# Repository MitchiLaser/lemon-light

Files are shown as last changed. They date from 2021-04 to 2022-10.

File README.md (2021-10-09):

# lemon-light
a couple of people trying to build a fancy monochrome LED display with bottles

## used bottles
We used lemonade bottles with 500 ml infill. The drinks boxes we bougth them inside had space for 26 bottles (4 x 6) and had a surface of 30cm x 40cm. Every box has its own controller which receives data via UART and drives the LEDs. The controllers can be connected in a dasy chain configuration.

## controllerboards

### slave

Every drink box has its own slave controller which is nothing more then an Attiny85 and 3 74hc595 shift registers. The Attiny receives the data via a UART interface, gets the first 3 bytes ans sends the rest to the next controller (also UART). Furthermore there is also an lm7805 attached because all boxes are powered via a voltage higher then 7,5V. This decision was made to prevent a voltage drop.

### master

The whole display is being controlled by a single master-controller which is made out of an ESP8266 and some electronics to translate the voltage for the serial interface between 3,3V and 5V. It is connected to a WiFi-interface and provides a web interface to control the boxes.

## 3D objects

There are some 3d printed objects that were used in the original build of this project: A part to hold the leds in the bottles and a box for the slave controller.

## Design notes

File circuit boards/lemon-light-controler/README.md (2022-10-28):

Main Controller Design
===
- parts used
  - node MCU
  - small buck converter breakout board
  - SN74HCT245N (although a one channel version of it would be better)
  - screw terminals for power supply and TX
- design
  - soldered on a breadboard
  - the buck converter provides 5V power supply
  - the RX pin is shifted with the SN74HCT245N from the 3.3V to the 5V level
- notes
  - make sure not to pull the TX of the node MCU low during boot
    (if you use a different level shifter)
  - during boot some data is output which causes the display to show random stuff
    - could be avoided by connecting the output enable pin of the SN74HCT245N
      to some GPIO of the node mcu

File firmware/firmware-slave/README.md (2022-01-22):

# Firmware for the slaves 
compile firmware with arduino ide and tinyMircroCore

## upload
use pyupdi

```pyupdi -d tiny406 -f firmware-slave.hex --fuses 2:0x02 6:0x04 8:0x00 -c /dev/ttyUSBx```

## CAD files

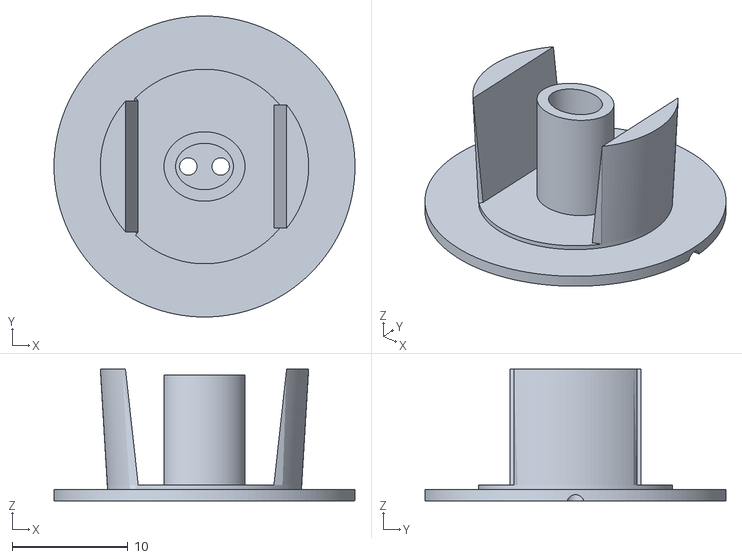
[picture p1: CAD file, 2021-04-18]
3d-objects/led_holder/HoliLight_led_holder.stl
26.0 x 26.0 x 11.4

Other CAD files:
3d-objects/led_holder/HoliLight_led_holder.blend

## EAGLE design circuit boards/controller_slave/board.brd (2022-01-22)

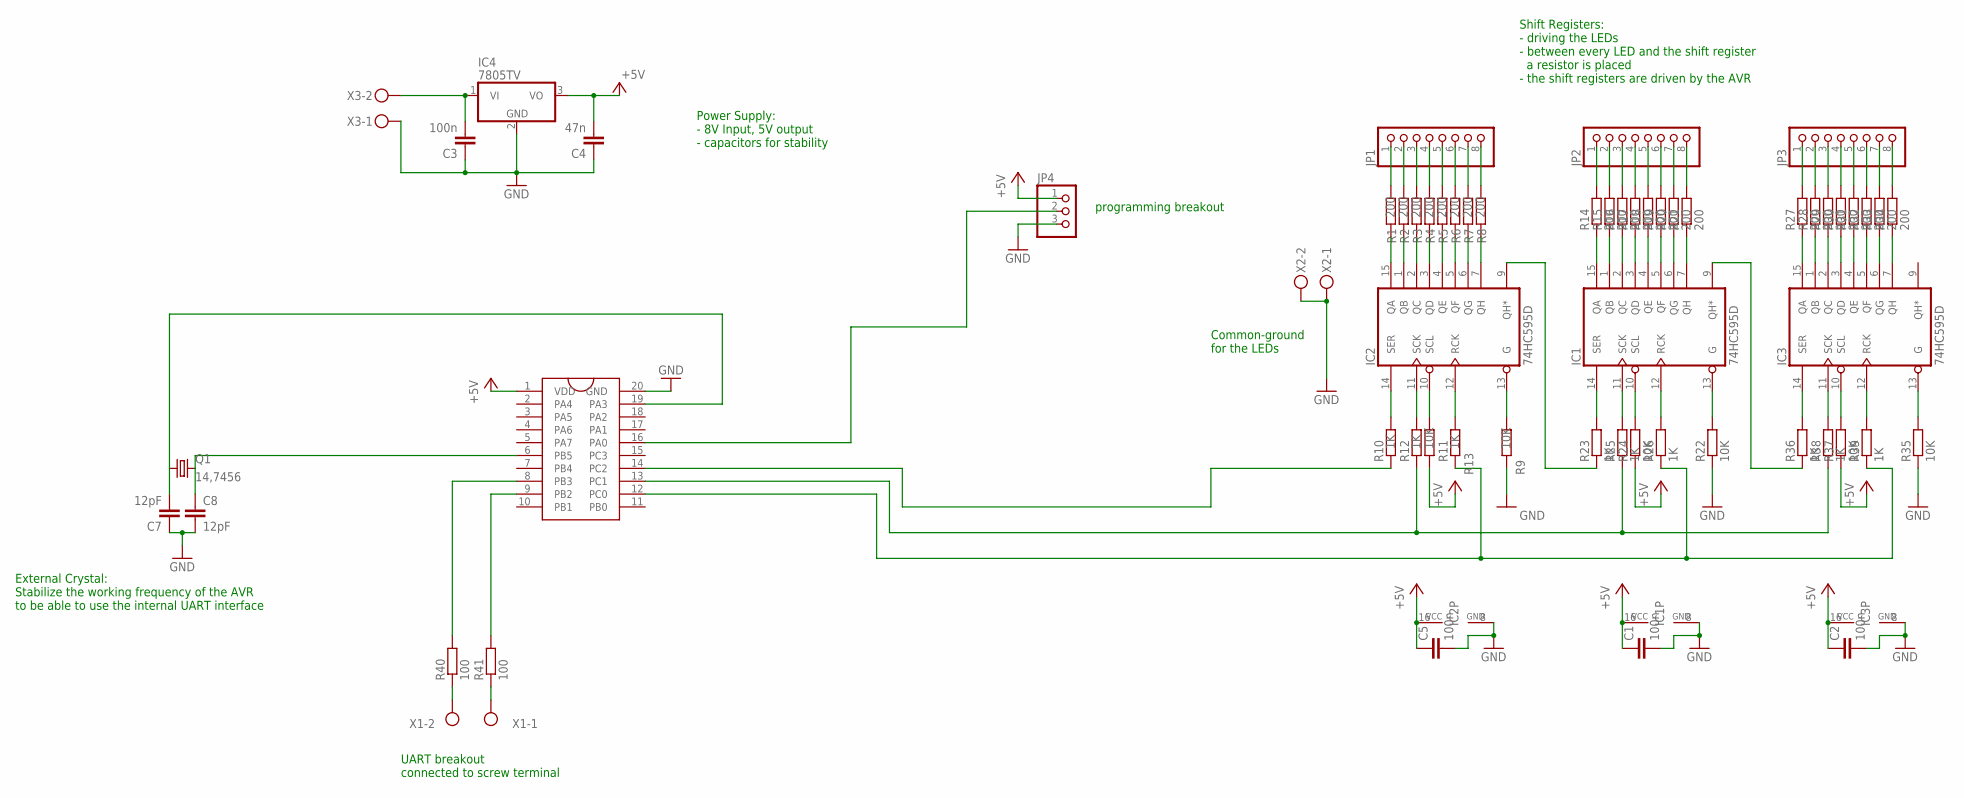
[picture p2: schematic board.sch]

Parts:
C1, C2, C3, C5: 100n; C0805K
C4: 47n; C0805K
C7, C8: 12pF; C0805K
IC1, IC2, IC3: 74HC595D; SO16
IC4: 7805TV; TO220V
JP1, JP2, JP3: PINHD-1X8; 1X08
JP4: PINHD-1X3; 1X03
Q1: 14,7456; SM49
R1, R2, R3, R4, R5, R6, R7, R8, R14, R15, R16, R17, R18, R19, R20, R21, R27, R28, R29, R30, R31, R32, R33, R34: 200; M0805
R9, R11, R22, R24, R35, R37: 10K; M0805
R10, R12, R13, R23, R25, R26, R36, R38, R39: 1K; M0805
R40, R41: 100; M0805
U$1: ATTINY406; SO20L
X1, X2, X3: MKDSN1,5/2-5,08

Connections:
+5V: C1.1, C2.1, C4.2, C5.1, IC1.16 (VCC), IC2.16 (VCC), IC3.16 (VCC), IC4.3 (VO), JP4.1, R11.1, R24.1, R37.1, U$1.1 (VDD)
GND: C1.2, C2.2, C3.1, C4.1, C5.2, C7.1, C8.2, IC1.8 (GND), IC2.8 (GND), IC3.8 (GND), IC4.2 (GND), JP4.3, R9.1, R22.1, R35.1, U$1.20 (GND), X2.1, X2.2, X3.1
unnamed: IC2.15 (QA), R1.1
unnamed: IC2.1 (QB), R2.1
unnamed: IC2.2 (QC), R3.1
unnamed: IC2.3 (QD), R4.1
unnamed: IC2.4 (QE), R5.1
unnamed: IC2.5 (QF), R6.1
unnamed: IC2.6 (QG), R7.1
unnamed: IC2.7 (QH), R8.1
unnamed: IC2.13 (G), R9.2
unnamed: IC2.14 (SER), R10.2
unnamed: IC2.11 (SCK), R12.2
unnamed: IC2.10 (SCL), R11.2
unnamed: IC2.12 (RCK), R13.2
unnamed: JP1.1, R1.2
unnamed: JP1.2, R2.2
unnamed: JP1.3, R3.2
unnamed: JP1.4, R4.2
unnamed: JP1.5, R5.2
unnamed: JP1.6, R6.2
unnamed: JP1.7, R7.2
unnamed: JP1.8, R8.2
unnamed: IC1.15 (QA), R14.1
unnamed: IC1.1 (QB), R15.1
unnamed: IC1.2 (QC), R16.1
unnamed: IC1.3 (QD), R17.1
unnamed: IC1.4 (QE), R18.1
unnamed: IC1.5 (QF), R19.1
unnamed: IC1.6 (QG), R20.1
unnamed: IC1.7 (QH), R21.1
unnamed: IC1.13 (G), R22.2
unnamed: IC1.14 (SER), R23.2
unnamed: IC1.11 (SCK), R25.2
unnamed: IC1.10 (SCL), R24.2
unnamed: IC1.12 (RCK), R26.2
unnamed: JP2.1, R14.2
unnamed: JP2.2, R15.2
unnamed: JP2.3, R16.2
unnamed: JP2.4, R17.2
unnamed: JP2.5, R18.2
unnamed: JP2.6, R19.2
unnamed: JP2.7, R20.2
unnamed: JP2.8, R21.2
unnamed: IC3.15 (QA), R27.1
unnamed: IC3.1 (QB), R28.1
unnamed: IC3.2 (QC), R29.1
unnamed: IC3.3 (QD), R30.1
unnamed: IC3.4 (QE), R31.1
unnamed: IC3.5 (QF), R32.1
unnamed: IC3.6 (QG), R33.1
unnamed: IC3.7 (QH), R34.1
unnamed: IC3.13 (G), R35.2
unnamed: IC3.14 (SER), R36.2
unnamed: IC3.11 (SCK), R38.2
unnamed: IC3.10 (SCL), R37.2
unnamed: IC3.12 (RCK), R39.2
unnamed: JP3.1, R27.2
unnamed: JP3.2, R28.2
unnamed: JP3.3, R29.2
unnamed: JP3.4, R30.2
unnamed: JP3.5, R31.2
unnamed: JP3.6, R32.2
unnamed: JP3.7, R33.2
unnamed: JP3.8, R34.2
unnamed: IC2.9 (QH*), R23.1
unnamed: IC1.9 (QH*), R36.1
unnamed: R40.1, X1.2
unnamed: R12.1, R25.1, R38.1, U$1.13 (PC1)
unnamed: R13.1, R26.1, R39.1, U$1.12 (PC0)
unnamed: R40.2, U$1.8 (PB3)
unnamed: R41.2, U$1.9 (PB2)
unnamed: R41.1, X1.1
unnamed: C3.2, IC4.1 (VI), X3.2
unnamed: R10.1, U$1.14 (PC2)
unnamed: C7.2, Q1.1, U$1.19 (PA3)
unnamed: JP4.2, U$1.16 (PA0)
unnamed: C8.1, Q1.2, U$1.6 (PB5)

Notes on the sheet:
UART breakout connected to screw terminal
Power Supply: - 8V Input, 5V output - capacitors for stability
Shift Registers: - driving the LEDs - between every LED and the shift register a resistor is placed - the shift registers are driven by the AVR
External Crystal: Stabilize the working frequency of the AVR to be able to use the internal UART interface
Common-ground for the LEDs
programming breakout

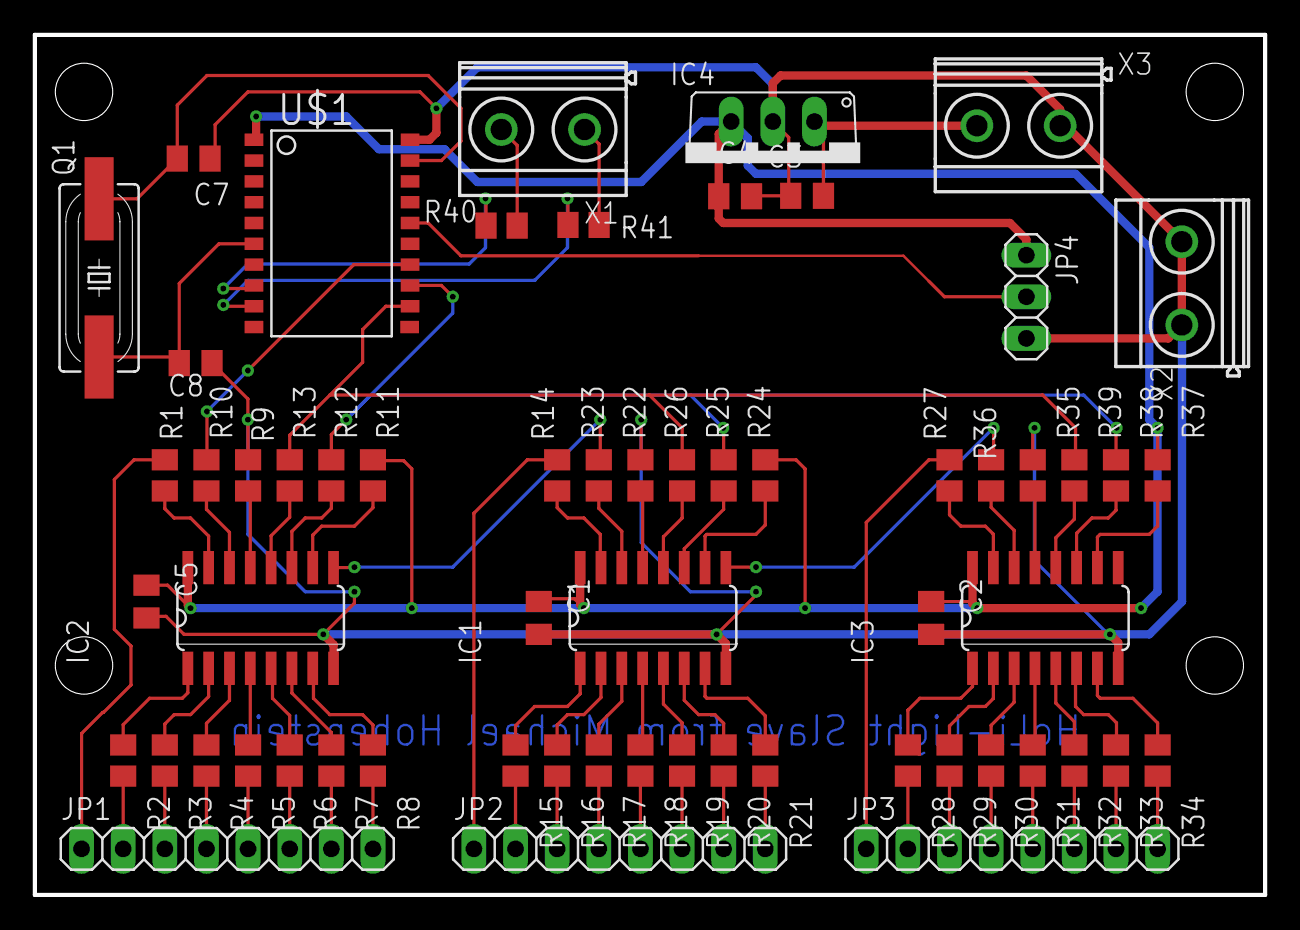
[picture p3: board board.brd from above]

Board: 2 copper layers, 75.1 x 52.5 mm, 61 parts (0 on the bottom side), 78 nets.

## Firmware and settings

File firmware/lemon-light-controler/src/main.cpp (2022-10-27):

/**
 * Firmware for the lemon-light project
 * 
 * Frank Hermann, 25 Oct 2022
 */

#include <Homie.h>

#define FW_NAME    "lemon-light-contoler"
#define FW_VERSION "1.0.0"
#define BRAND      "A4-IOT"


enum error_type{
  LINE_TO_LONG,
  LINE_TO_SHORT,
  BUFFER_FULL,
  UNKNOWN_SYMBOL,
  NO_ERROR
};

struct box_pos{
  int col, row;
  bool flip_cols, flip_rows;
};

HomieNode node("lemon-light", "Display", "lemon-light");
constexpr unsigned long baud = 115200;
constexpr int max_fb_size = 1024;
constexpr int ROWS_PER_BOX = 4;
constexpr int COLS_PER_BOX = 6;
static_assert(ROWS_PER_BOX*COLS_PER_BOX%8 == 0);
char fb[max_fb_size], box_buf[ROWS_PER_BOX*COLS_PER_BOX/8];
int fb_rows = 0, fb_cols = 0;
int row_pos = 0, col_pos = 0;
int row_offset = 0, col_offset = 0;
int row_speed = 0, col_speed = 5;
unsigned int max_fps = 100;
unsigned long start_scrolling_time, last_refresh;
bool scrolling_enabled = false;
bool need_refresh = true;
int max_col_scroll = 0, max_row_scroll = 0;
box_pos box_order[] = {{0, 1, false, false}, {1, 1, false, false}, {2, 1, false, false}, {3, 1, false, false},
                       {3, 0,  true,  true}, {2, 0,  true,  true}, {1, 0,  true,  true}, {0, 0,  true,  true}};

void set_err(const error_type err){
  const char *err_str;
  switch(err){
    case LINE_TO_LONG: err_str = "LINE_TO_LONG"; break;
    case LINE_TO_SHORT: err_str = "LINE_TO_SHORT"; break;
    case BUFFER_FULL: err_str = "BUFFER_FULL"; break;
    case UNKNOWN_SYMBOL: err_str = "UNKNOWN_SYMBOL"; break;
    default: err_str = "UNKNOWN_ERROR";
  }
  node.setProperty("error").send(err_str);
}

bool add_nibble(int &nibbles_in_buf, const char nibble){
    if(nibbles_in_buf/2 == max_fb_size){
      set_err(BUFFER_FULL);
      return false;
    }
    if(nibbles_in_buf%2 == 0){
      fb[nibbles_in_buf/2] = nibble;
      fb[nibbles_in_buf/2] <<= 4;
    }else{
      fb[nibbles_in_buf/2] |= nibble;
    }
    nibbles_in_buf++;
    return true;
}

bool col_pos_handler(const HomieRange &range, const String &value){
  col_pos = value.toInt();
  need_refresh = true;
  return true;
}

bool row_pos_handler(const HomieRange &range, const String &value){
  row_pos = value.toInt();
  need_refresh = true;
  return true;
}

void reset_scrolling(){
  start_scrolling_time = millis();
  need_refresh = true;
  col_offset = 0;
  row_offset = 0;
}

bool frame_handler(const HomieRange &range, const String &value){
  fb_cols = 0;
  fb_rows = 0;
  int nibbles_in_buf = 0, nibbles_in_col = 0;
  for(const char c : value){
    if(c == '\n'){
      if(nibbles_in_col == 0){
        continue;
      }
      if(fb_rows == 0){
        fb_rows = nibbles_in_col*4;
      }else if(nibbles_in_col < fb_rows/4){
        set_err(LINE_TO_SHORT);
        for(; nibbles_in_col < fb_rows/4; nibbles_in_col++){
          if(!add_nibble(nibbles_in_buf, 0)){
            reset_scrolling();
            return true;
          }
        }
      }
      fb_cols++;
      nibbles_in_col = 0;
      continue;
    }
    char nibble;
    if(isdigit(c)){
      nibble = c - '0';
    } else if (c >= 'A' && c <= 'F') {
      nibble = c + 10 - 'A';
    }else{
      set_err(UNKNOWN_SYMBOL);
      continue;
    }
    nibbles_in_col++;
    if(nibbles_in_col*4 > fb_rows && fb_rows != 0){
      set_err(LINE_TO_LONG);
      continue;
    }
    if(!add_nibble(nibbles_in_buf, nibble)){
      reset_scrolling();
      return true;
    }
  }
  reset_scrolling();
  return true;
}

bool scrolling_handler(const HomieRange &range, const String &value){
  scrolling_enabled = value == "true";
  reset_scrolling();
  return true;
}

bool force_refresh_handler(const HomieRange &range, const String &value){
  if(value == "true"){
    need_refresh = true;
    return true;
  }
  return false;
}

bool max_row_scroll_handler(const HomieRange &range, const String &value){
  max_row_scroll = value.toInt();
  reset_scrolling();
  return true;
}

bool max_col_scroll_handler(const HomieRange &range, const String &value){
  max_col_scroll = value.toInt();
  reset_scrolling();
  return true;
}

bool col_speed_handler(const HomieRange &range, const String &value){
  col_speed = value.toInt();
  reset_scrolling();
  return true;
}

bool row_speed_handler(const HomieRange &range, const String &value){
  row_speed = value.toInt();
  reset_scrolling();
  return true;
}

/*
   bit order for every box

    +-------------------+
    | 00 04 08 0C 10 14 |
    | 01 05 09 0D 11 15 |
    | 02 06 0A 0E 12 16 |
    | 03 07 0B 0F 13 17 |
    +-------------------+

     box numberering

      +-----+-----+
      | 0,0 | 1,0 |
      +-----+-----+
      | 0,1 | 1,1 |
      +-----+-----+
  
  note: the bit order for fb is the column wise (the same as for the box)
        and fb_rows is a multiple of 4
*/
void write_frame(){
  for(box_pos &p : box_order){
    memset(box_buf, 0, ROWS_PER_BOX*COLS_PER_BOX/8);
    for(int c = 0; c < COLS_PER_BOX; c++){
      for(int r = 0; r < ROWS_PER_BOX; r++){
        int c_fb = p.col*COLS_PER_BOX + col_pos + col_offset + c;
        int r_fb = p.row*ROWS_PER_BOX + row_pos + row_offset + r;
        if(c_fb >= 0 && r_fb >= 0 && c_fb < fb_cols && r_fb < fb_rows){
          int box_c = c;
          if(p.flip_cols){
            box_c = COLS_PER_BOX - 1 - c;
          }
          int box_r = r;
          if(p.flip_rows){
            box_r = ROWS_PER_BOX - 1 - r;
          }
          int offset_box = box_c*ROWS_PER_BOX + box_r;
          int offset_fb = c_fb*fb_rows + r_fb;
          char val = (fb[offset_fb/8] >> (7 - offset_fb%8)) & 1;
          box_buf[offset_box/8] |= val << (offset_box%8);
        }
      }
    }
    Serial.write(box_buf, ROWS_PER_BOX*COLS_PER_BOX/8);
  }
  Serial.flush();
}

void homie_loop(){
  unsigned long now = millis();
  if(scrolling_enabled){
    int new_row_offset = int(now - start_scrolling_time)*row_speed/1000;
    int new_col_offset = int(now - start_scrolling_time)*col_speed/1000;
    if((max_row_scroll > 0 && max_row_scroll <= abs(new_row_offset)) ||
       (max_col_scroll > 0 && max_col_scroll <= abs(new_col_offset))){
      start_scrolling_time = now;
      new_col_offset = 0;
      new_row_offset = 0;
    }
    need_refresh |= new_row_offset != row_offset;
    need_refresh |= new_col_offset != col_offset;
    row_offset = new_row_offset;
    col_offset = new_col_offset;
  }
  if(need_refresh && now - last_refresh >= 1000u/max_fps){
    write_frame();
    need_refresh = false;
    last_refresh = now;
  }
}
  
void setup(){
  Homie.disableLogging();
  Serial.begin(baud);
  Homie.setLoopFunction(homie_loop);
  Homie_setBrand(BRAND);
  Homie_setFirmware(FW_NAME, FW_VERSION);
  node.advertise("frame").settable(frame_handler);
  node.advertise("force_refresh").settable(force_refresh_handler);
  node.advertise("col-pos").settable(col_pos_handler);
  node.advertise("row-pos").settable(row_pos_handler);
  node.advertise("col-speed").settable(col_speed_handler);
  node.advertise("row-speed").settable(row_speed_handler);
  node.advertise("scrolling").settable(scrolling_handler);
  node.advertise("max-row-scroll").settable(max_row_scroll_handler);
  node.advertise("max-col-scroll").settable(max_col_scroll_handler);
  node.advertise("error");
  Homie.setup();
}

void loop(){
  Homie.loop();
}

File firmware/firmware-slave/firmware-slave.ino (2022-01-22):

// ===== configuration =====


// baud rate for serial connection
#define serial_baud 115200

// pins attached to the shift registers
#define shift_data 12
#define shift_clock 11
#define store_clock 10


const byte len_buffer = 3;

// ===== configuration end =====

// states for the state machine driving the whole device
enum State {S_INIT = 0, S_IDLE = 1, S_FIRST = 2, S_RECEIVE = 3, S_OUTPUT = 4, S_PASS = 5};
State sm_state; // store the current state

// output buffer
byte buffer[ len_buffer ] = {0};
byte buffer_pointer;

unsigned long int timer = 0;
unsigned long int timeout = 20; // in milliseconds
unsigned long int current_time;


// flush buffer to shift registers
void out_buffer( void ) {

  digitalWrite(store_clock, LOW);
  for (int i = len_buffer - 1; i >= 0; i--) {
    shiftOut(shift_data, shift_clock, MSBFIRST, buffer[i] );
  }
  digitalWrite(store_clock, HIGH);

}


void setup() {
  // initialiation
  sm_state = S_INIT;

  // initialize serial interface
  Serial.begin(serial_baud);

  // intialize GPIO Pins to drive shift register
  pinMode(shift_data, OUTPUT);
  pinMode(shift_clock, OUTPUT);
  pinMode(store_clock, OUTPUT);

  // set buffer pointer to 0
  buffer_pointer = 0;

  // output 0x000000 to reset all shift registers
  out_buffer();

  // next state
  sm_state = S_IDLE;
}


void loop() {
  
  switch (sm_state) {
    case S_IDLE:
      if ( Serial.available() )
        sm_state = S_FIRST;
      break;

    case S_FIRST:
      buffer_pointer = 0;
      buffer[ buffer_pointer ] = Serial.read();
      buffer_pointer++;
      timer = millis();
      sm_state = S_RECEIVE;
      break;

    case S_RECEIVE:
      current_time = millis();

      if (Serial.available()) {
        buffer[ buffer_pointer ] = Serial.read();
        buffer_pointer++;
        timer = millis();
        if (buffer_pointer < len_buffer) {
          sm_state = S_RECEIVE;
        } else {
          sm_state = S_OUTPUT;
        }
      } else {
        if ( current_time > timeout + timer) {
          sm_state = S_IDLE;
        }
      }
      break;

    case S_OUTPUT:
      out_buffer();
      timer = millis();
      sm_state = S_PASS;
      break;

    case S_PASS:
      current_time = millis();

      if ( Serial.available() ) {
        byte received = Serial.read();
        Serial.write( received );
        timer = millis();
      } else {
        if ( current_time > timeout + timer) {
          sm_state = S_IDLE;
        }
      }
      break;

  }

}

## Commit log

2020-04-14 added Eagle scematic and pcb files for controller (slave)
    [board.brd, board.sch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]
2021-01-01 prototype of firmware ready
    [board.brd, board.sch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]
2021-04-10 add 3D moddels off the LED Holders
    [HoliLight_led_holder.blend, HoliLight_led_holder.stl]
2021-04-28 Design Controller Master
    [scematics.brd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]
2021-04-28 cleaning up and adding some documentation
    [HoliLight_led_holder.blend, HoliLight_led_holder.stl]
2021-05-18 added 3d model of the holder for the slave-controller circuit board inside the boxes
    [cage.ipt, cage.stl]
2021-05-18 fixed an issue with an unnecessary edge in the 3d objects
    [cage.ipt, cage.stl]
2021-06-02 Daughterboard und BSS-lib
    [daughterboard.brd, daughterboard.sch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]
2021-06-03 redesign slave pcb no daugtherboard needed
2021-06-03 update slave pcb: better connection to quarz
    [board.brd, cage.ipt, cage.stl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]
2021-06-03 reorganised structure
    [board.brd, board.sch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]
2021-10-09 changed PCB: mostly SMD parts
    [board.brd, board.sch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]
2021-10-09 Controller Slave: Lastkapazität Quarz und UPDI Schnittstelle angepasst
    [board.brd, board.sch]
2021-10-20 fixed minor issue: two power lanes were to close to each other
    [copper_bottom.gbr, copper_top.gbr, drill_1_16.xln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]
2022-01-22 removed reset circuit from board design
    [board.brd, board.sch]
2022-10-28 replace master controller board with description of breadboard design
    [scematics.brd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]
2022-10-28 deleted unused cage 3d object
    [cage.ipt, cage.stl]
